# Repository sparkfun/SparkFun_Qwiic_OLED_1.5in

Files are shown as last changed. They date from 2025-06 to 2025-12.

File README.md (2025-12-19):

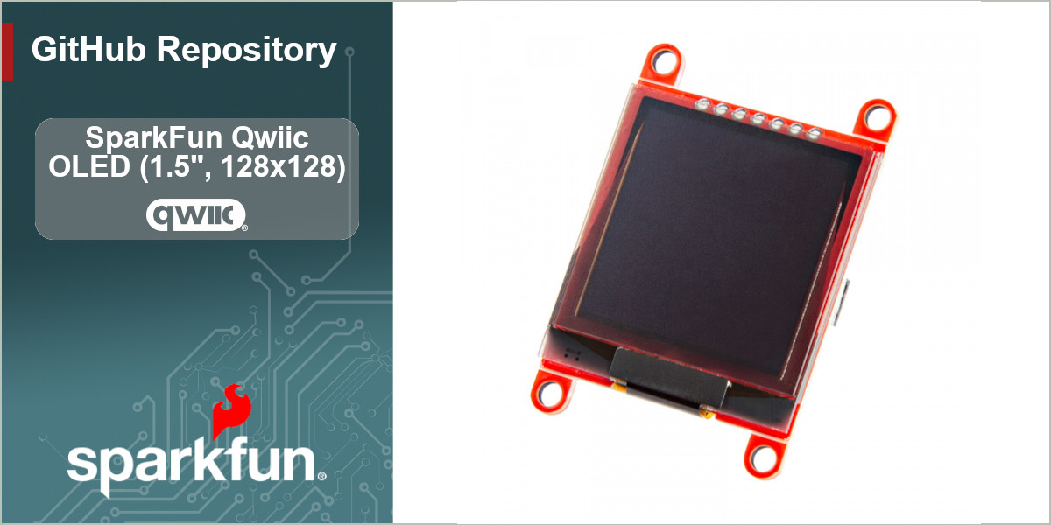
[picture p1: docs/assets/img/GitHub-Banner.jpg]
SparkFun Qwiic OLED 1.5in (https://www.sparkfun.com/sparkfun-qwiic-oled-display-1-5-in-128x128.html)


--------------------------

The SparkFun Qwiic OLED Display offers a sharp, professional user interface in a compact 1.5-inch form factor. Featuring a 128x128-pixel resolution, this monochrome white-on-black display uses Chip-on-Glass (COG) OLED technology, providing a 1:1 aspect ratio and a high-pixel-density canvas ideal for custom graphics and data plotting. Because OLED pixels emit their own light, no bulky backlight is required, resulting in superior image quality and "deeper blacks" compared to traditional LCDs.

Repository Contents
-------------------

* **/Documents** - Data sheets, additional product information
* **/Hardware** - Eagle design files (.brd, .sch)
* **/Production** - Production panel files (.brd)
* **/docs** - Documentation files for Hookup Guide content

Documentation
--------------
* **[Library](https://github.com/sparkfun/SparkFun_Qwiic_OLED_Arduino_Library)** - Arduino library for the SparkFun Qwiic OLEDs.
* **[Hookup Guide](https://docs.sparkfun.com/SparkFun_Qwiic_OLED_1.5in/introduction/#)** - Basic hookup guide for the SparkFun Qwiic OLED Display (1.5 in., 128x128).

Product Versions
----------------
* [LCD-29530](https://www.sparkfun.com/sparkfun-qwiic-oled-display-1-5-in-128x128.html) - Initial release of the Qwiic OLED Display (1.5" 128x128)

License Information
-------------------

This product is _**open source**_! 

Please review the LICENSE.md file for license information. 

If you have any questions or concerns on licensing, please contact technical support on our [SparkFun forums](https://forum.sparkfun.com/viewforum.php?f=152).

Distributed as-is; no warranty is given.

- Your friends at SparkFun.

_<COLLABORATION CREDIT>_

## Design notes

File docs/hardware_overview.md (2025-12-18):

Let's take a closer look at the OLED and other hardware included on this breakout board.

## WEO128128HWAP3N00000 OLED

This COG (Chip on Glass) OLED display from Winstar Displays is a 1.5" square monochrome white on black display. It has a 128x128 pixel dot matrix display with an active area of 28.86mm x 28.86mm. 

This OLED uses the CH1120 display driver IC. The board also includes a AP3012 boost circuit to output 12V to boost the contrast of the OLED.

## Connectors

## Power

The board's power is supplied through either one of the Qwiic connectors or through the dedicated PTH power pins (3.3V and GND). The board expects a supply voltage of 3.3V and runs at the same logic level. 

## LED

The sole LED on the board is a red LED labeled PWR. This LED illuminates when the 3.3V rail is powered.

## Solder Jumpers

This Qwiic OLED Display has five solder jumpers labeled <b>IM1</b>, <b>IM2</b>, <b>ADDR</b>, <b>LED</b> and <b>I<sup>2</sup>C</b>. The list below outlines the functionality of each jumper along with notes on their use.

* <b>IM1</b>/<b>IM2</b> - These two jumpers control the communication interface to the OLED. With both jumpers OPEN the OLED communicates over I<sup>2</sup>C. With both jumpers CLOSED the OLED communicates over SPI. Both jumpers are OPEN by default to enable the I<sup>2</sup>C interface. Both jumpers must be in the same state for either communication interface.
* <b>ADDR</b> - The ADDR jumper sets the I<sup>2</sup>C address of the OLED. The jumper is OPEN by default and sets the I<sup>2</sup>C address to <b>0x3C</b>. Close the solder jumper to change the address to <b>Ox3D</b>.
* <b>LED</b> - This solder jumper completes the power LED circuit to enable the red power LED. It is CLOSED by default. Open the jumper to disable the power LED if needed.
* <b>I<sup>2</sup>C - This three-way solder jumper pulls the I<sup>2</sup>C lines (SDA and SCL) to <b>3.3V</b> through a pair of <b>2.2k&ohm;</b> resistors. Open the jumper completely to disable the pullups on these lines.

## Board Dimensions

The main dimensions of the Qwiic OLED Display measure 1.350" x 1.475" (34.290mm x 37.465) and it has four mounting standoffs outside the main dimensions that fit a 4-40 screw.

<figure markdown>
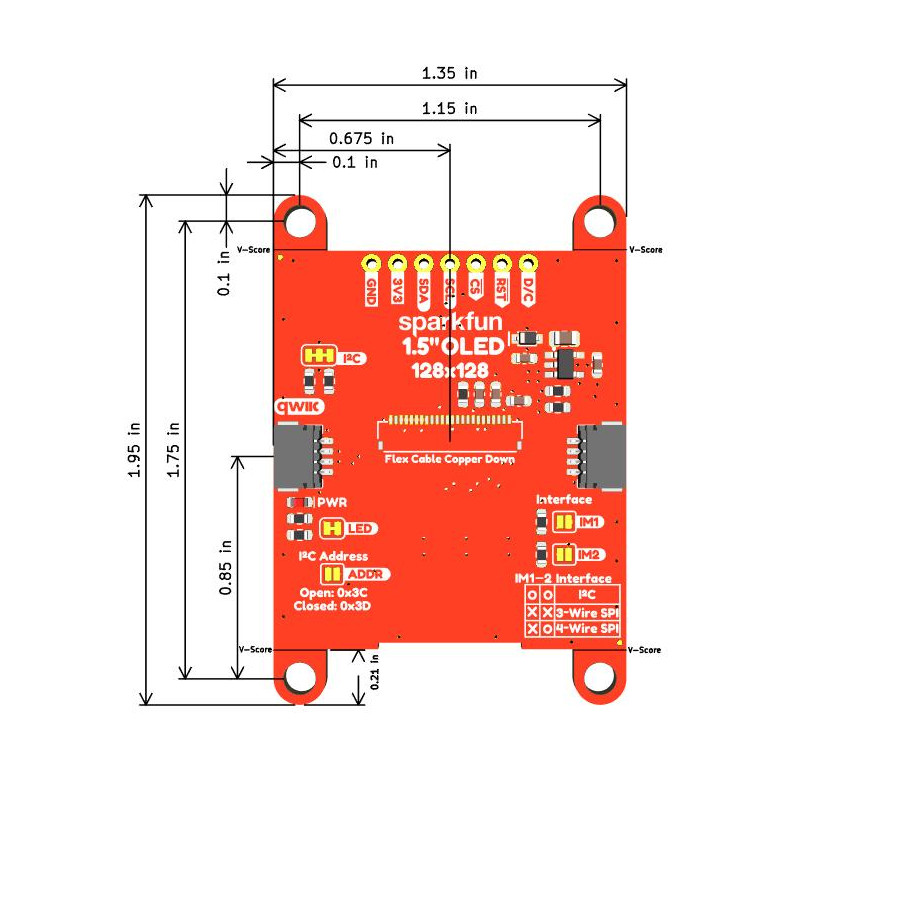
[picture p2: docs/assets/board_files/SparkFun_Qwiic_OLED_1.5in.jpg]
Board Dimensions

</figure>

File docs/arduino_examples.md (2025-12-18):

Let's take a look at a few of the examples included in the SparkFun Qwiic OLED Arduino Library

## Example 01 - Hello

The first example in the Qwiic OLED library shows the basic setup of the library and generates a simple text display of "Hello". Open the example by navigating to **File** > **Examples** > **SparkFun Qwiic OLED Arduino Library** > **Example-01_Hello**. All the examples included in the library work with the five supported Qwiic OLEDs with a simple adjustment to a couple lines in the start of the sketch. The examples default to select the Qwiic Micro OLED so we need to adjust the definition to switch to the 1.5" OLED. Comment out the line for the Qwiic Micro OLED and uncomment the line for the Qwiic 1.5" OLED like the code below:

``` c++
//QwiicMicroOLED myOLED;
//QwiicTransparentOLED myOLED;
//QwiicNarrowOLED myOLED;
//Qwiic1in3OLED myOLED;
Qwiic1in5OLED myOLED;
```
After selecting the correct OLED, select your Board and Port and click the "Upload" button. Once the code finishes uploading the display should initialize and display a static text print saying "Hello" like the photo below:

<figure markdown>
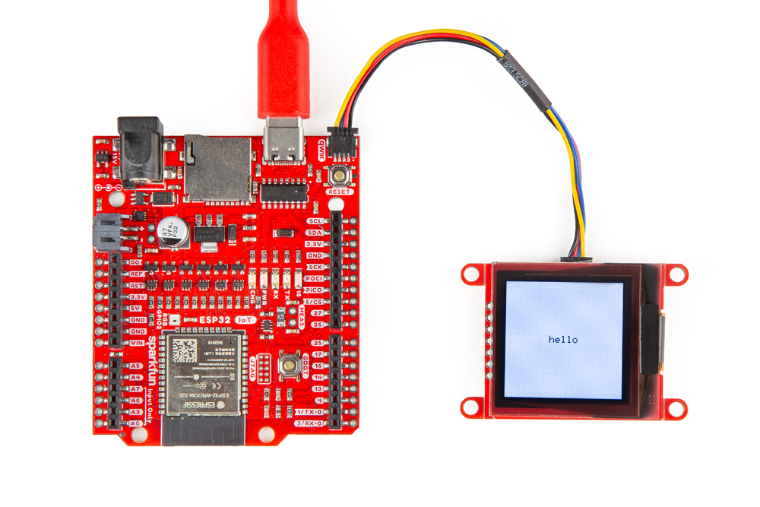
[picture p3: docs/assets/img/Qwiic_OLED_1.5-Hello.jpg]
Photo of the Qwiic OLED 1.5 displaying "Hello"

</figure>

## Example 02 - Shapes

The second example demonstrates various methods for drawing shapes using the library. Open the example by navigating to **File** > **Examples** > **SparkFun Qwiic OLED Arduino Library** > **Example-02_Shapes**. Remember we need to adjust the code to work with the OLED 1.5" so make sure to adjust the definitions like we did for Example 01 before uploading. After adjusting the OLED definition, click the "Upload" button. Once the code finishes uploading, the display will initialize and start drawing various shapes using different drawing methods to create various types of lines, rectangles and circles like the video below shows:

<figure markdown>
Short video showing the Qwiic OLED 1.5 displaying various shapes and lines
</figure>

## Example 06 - Clock

The sixth example draws a clock face on the OLED that updates roughly every second to keep time. Open the example by navigating to **File** > **Examples** > **SparkFun Qwiic OLED Arduino Library** > **Example-06_Clock**. Adjust the OLED defines to select the 1.5" display and if you want to have it keep accurate time, you can set the initial time by adjusting the initial variables for hours, minutes and seconds:

``` c++
// Use these variables to set the initial time
int hours = 11;
int minutes = 50;
int seconds = 30;
```

Upload the code and when it finishes, the display will initialize with a clock face like the image below:

<figure markdown>
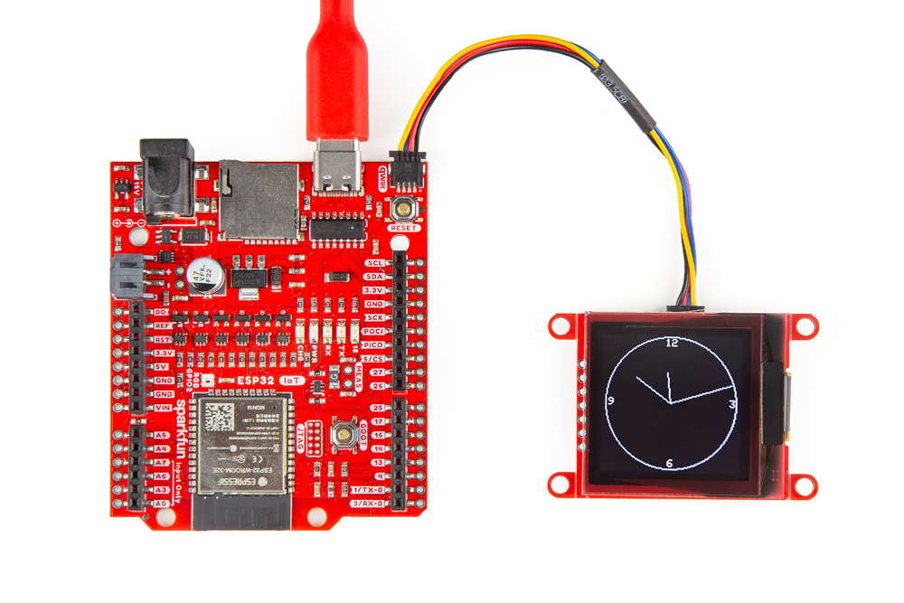
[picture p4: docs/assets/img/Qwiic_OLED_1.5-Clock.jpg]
Photo showing the OLED displaying a clock face

</figure>

## Example 07 - Cube

The last example we'll cover here is Example 07 - Cube. This example creates a cube in the center of the display that rotates around its center point. Open the example by navigating to **File** > **Examples** > **SparkFun Qwiic OLED Arduino Library** > **Example-07_Cube**. 

<figure markdown>
Short video showing the cube demo on the Qwiic OLED 1.5
</figure>

This example has plenty of variables we can adjust to change things like the size, location and rotation speed of the cube. For the video above, we doubled the size of the cube to make it easier to see. Try playing around with the different variables and re-uploading it to change the appearance and movement of the cube.

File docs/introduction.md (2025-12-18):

<figure markdown>
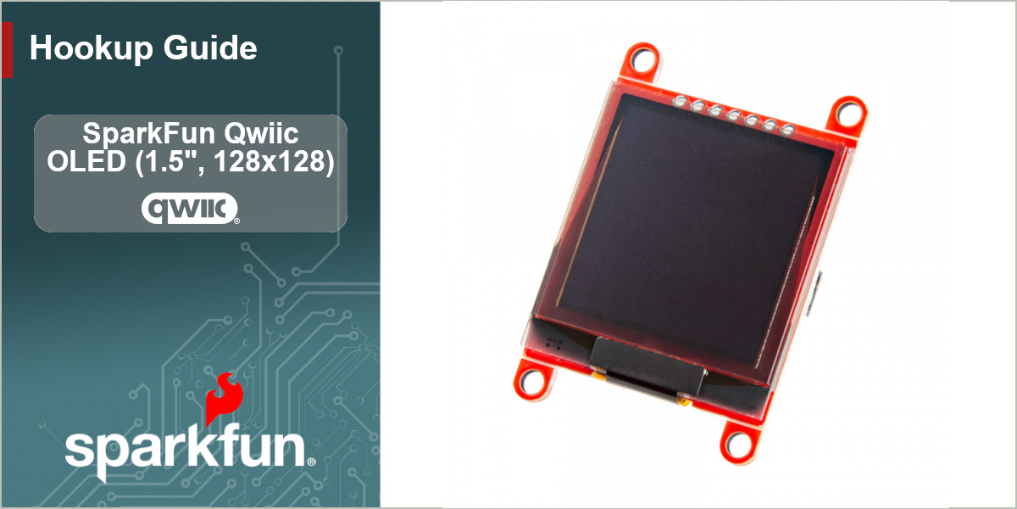
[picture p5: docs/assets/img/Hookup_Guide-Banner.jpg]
Banner Image (https://www.sparkfun.com/sparkfun-qwiic-oled-display-1-5-in-128x128.html)

</figure>

The SparkFun Qwiic OLED Display (1.5in., 128x128) is a compact, square monochrome white on black 128x128 pixel display. This COG (chip on glass) OLED display does not have a back light layer (unlike LCDs) so it’s thinner, consumes less power, and has higher contrast. 

You'll need the Qwiic OLED Display (1.5in., 128x128) along with the following products to follow along with this tutorial:

* [SparkFun RedBoard IoT - ESP32](https://www.sparkfun.com/sparkfun-redboard-plus.html) or other Arduino development board
* [Qwiic Cable]()
* [USB-C Cable](https://www.sparkfun.com/reversible-usb-a-to-c-cable-0-8m.html)

## Topics Covered

This document contains three main sections: **Quickstart Guide**, **Hardware** and **Software**. 

The Quickstart Guide assumes a working knowledge of how to assemble and use the Qwiic OLED Display with a Qwiic-enabled development board. It covers basic Qwiic assembly then jumps right into getting the necessary software packages installed to start uploading code and displaying text and images in just a few short minutes.

The Hardware pages cover a hardware overview that provides a detailed overview of the Qwiic OLED Display (1.5in., 128x128) covering all the major components on the board in detail as well as a hardware assembly page which goes over the steps required to assemble and use board with a compatible Arudino board.

The Software pages give instructions on installing the SparkFun OLED Arduino library and using the examples included in it.

## Resources and Documentation

You'll find the board design files (KiCad files & schematic), relevant documentation (datasheets, white papers, etc.) and other helpful links in the **Resources**. Lastly, the **Support** section includes a Troubleshooting page that includes any helpful tips specific to this board as well as information on how to receive technical support from SparkFun.

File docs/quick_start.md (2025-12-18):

In this Quick Start guide we'll connect the SparkFun OLED Display (1.5in., 128x128) to a SparkFun IoT RedBoard - ESP32 and use the SparkFun Qwiic OLED Arduino library to produce a rotating cube on the display.

<figure markdown>
Short video showing cube demo on the OLED
</figure>

If you're not familiar with using breakout and development boards or the Arduino IDE, refer to the [Hardware](./hardware_overview.md) & [Software](./arduino_setup.md) sections for a detailed overview of the board along with instructions on soldering to and connecting the breakout, installing and using the SparkFun MY1690X MP3 Decoder Arduino Library.

## Basic Assembly

With the Qwiic Ecosystem all you'll need to do to assemble the Qwiic OLED - 1.5" is the following steps:

* Connect the Qwiic OLED Display to the RedBoard IoT - ESP32 using a Qwiic cable.
* Connect the RedBoard IoT - ESP32 to your computer with a USB-C cable.

<figure markdown>
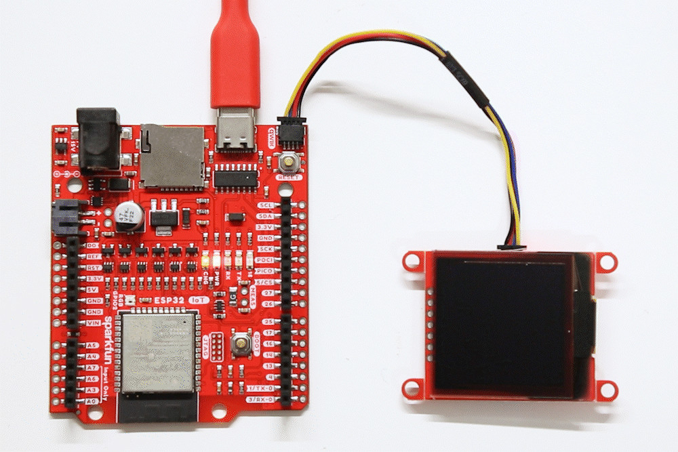
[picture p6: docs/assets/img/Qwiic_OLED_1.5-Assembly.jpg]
Completed Qwiic assembly
[]
</figure>

## Arduino Example

Let's move on to installing the SparkFun Qwiic OLED Arduino library (and boards packages if needed) to . Follow these steps to upload and run the "Cube" example.

* Install the SparkFun Qwiic OLED Arduino library using the [library manager](https://docs.arduino.cc/software/ide-v2/tutorials/ide-v2-installing-a-library/) by searching for "SparkFun Qwiic OLED".
* If you don't already have the RedBoard IoT - ESP32 board definition installed, you'll need to install the "esp32" boards package by Espressif Systems. Copy this JSON URL: <code>https://espressif.github.io/arduino-esp32/package_esp32_dev_index.json
</code> to the "Additional Boards Manager URLs" in the "Preferences" menu and then search for "esp32" in the [boards manager](https://docs.arduino.cc/software/ide-v2/tutorials/ide-v2-board-manager) tool and install the latest version of the "esp32 by Espressif Systems" boards package.
* Open "Example-07_Cube" from the SparkFun Qwiic OLED Arduino library folder. Comment out the line for the Qwiic Micro OLED and uncomment the line for the Qwiic 1.5" OLED like the code below:

``` c++
//QwiicMicroOLED myOLED;
//QwiicTransparentOLED myOLED;
//QwiicNarrowOLED myOLED;
//Qwiic1in3OLED myOLED;
Qwiic1in5OLED myOLED;
```

* Select your Board and Port and click the "Upload" button.

Once the code finishes compiling and uploading, the OLED should display a rotating cube similar to the video below:

<figure markdown>
Short video showing cube demo on the OLED
</figure>

This example has plenty of variables we can adjust to change things like the size, location and rotation speed of the cube. For the video above, we doubled the size of the cube to make it easier to see. Try playing around with the different variables and re-uploading it to change the appearance and movement of the cube.

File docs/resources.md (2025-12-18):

Refer to the following resources for more information about the SparkFun Qwiic OLED (1.5in., 128x128):

* [Schematic](./assets/board_files/SparkFun_Qwiic_OLED_1.5in.pdf)
* [KiCad Files](./assets/board_files/SparkFun_Qwiic_OLED_1.5in.zip)
* [Board Dimensions](./assets/board_files/SparkFun_Qwiic_OLED_1.5in.jpg)
* [Datasheet](./assets/component_documentation/WEO128128HWAP3N00000.pdf) (WEO128128HWAP3N00000)
* [Datasheet](./assets/component_documentation/CH1120.V0.9.pdf) (CH1120)
* [OLED Arduino Library](https://github.com/sparkfun/SparkFun_Qwiic_OLED_Arduino_Library)
* [GitHub Repository](https://github.com/sparkfun/SparkFun_Qwiic_OLED_1.5in)

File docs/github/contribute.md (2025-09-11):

# Contribute: Make an Augmentation!
Spot an improvement opportunity? Feel free to contribute to our open-source design and documentation. 

## :material-file-document-multiple:&nbsp;Improve our Documentation
All of this documentation can be modified by you! Please help us make it better.

* These pages are contained in the [`docs` folder](https://github.com/sparkfun/SparkFun_Qwiic_OLED_1.5in/tree/main/docs) of the [SparkFun Qwiic OLED Display (1.5in, 128x128) repository](https://github.com/sparkfun/SparkFun_Qwiic_OLED_1.5in).

<!-- ### :material-source-pull:&nbsp;Submit a Correction -->
### Submit a Correction

1. With a GitHub account, [fork this repository](https://github.com/sparkfun/SparkFun_Qwiic_OLED_1.5in/fork).
2. Add your corrections or improvements to the markdown file.
3. File a pull request with your changes, and enjoy making the ~~words~~ ~~worlds~~ world a better place.
	* Once received, the documentation specialist will automatically be notified.
	* We will review your suggested improvements to make sure they are correct and fit within our documentation standards.

## :material-cog:&nbsp;Improve our Hardware Design
All of our designs are open-source! Please help us make it better.

* Our board design files are contained in the [`Hardware` folder](https://github.com/sparkfun/SparkFun_Qwiic_OLED_1.5in/tree/main/Hardware) of the [SparkFun Qwiic OLED Display (1.5in, 128x128) repository](https://github.com/sparkfun/SparkFun_Qwiic_OLED_1.5in).

<!-- ### :material-source-pull:&nbsp;Submit a Design Enhancement -->
### Submit a Design Enhancement

1. With a GitHub account, [fork this repository](https://github.com/sparkfun/SparkFun_Qwiic_OLED_1.5in/fork).
2. Add your design augmentation(s)
3. File a pull request with your changes, and enjoy making the ~~words~~ ~~worlds~~ world a better place.
	1. Once received, the engineer in charge of the original design will automatically be notified.
	2. We will review your suggested improvement(s) to verify that they are within our board design standards and meet our product design requirements.
	3. If approved, we will flag these changes for our next board revision. Congrats! 🍻

		!!! info
			Even if your suggestion is accepted, these changes may not be immediately available for purchase. We may have to cycle through our current product inventory first.

## Contributors&nbsp;:clap:
Let's provide some recognition to the contributors for this project!

GitHub Contributors Image
<br>


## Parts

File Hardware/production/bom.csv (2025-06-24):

Designator | Footprint | Quantity | Value | LCSC Part #
C1, C2 | 603 | 2 | 1.0uF
C3, C4, C5 | 603 | 3 | 4.7uF
D1 | 603 | 1 | Red
D2 | SOD-323 | 1 | PMEG4005EJ
J1, J2 | JST_SMD_1.0mm-4_Black | 2 | Qwiic_RA
J3 | 1x06 | 1 | Conn_01x06
J4 | FPC_0.5mm-24 | 1 | Conn_01x24_FPC
L1 | 805 | 1 | 10uH
R10, R11, R7 | 603 | 3 | 10k
R12 | 603 | 1 | 68.1k
R3 | 603 | 1 | 4.7k
R4, R5 | 603 | 2 | 2.2k
R6 | 603 | 1 | 569k
R9 | 603 | 1 | 7.5k
U5 | SOT23-5 | 1 | AP3012

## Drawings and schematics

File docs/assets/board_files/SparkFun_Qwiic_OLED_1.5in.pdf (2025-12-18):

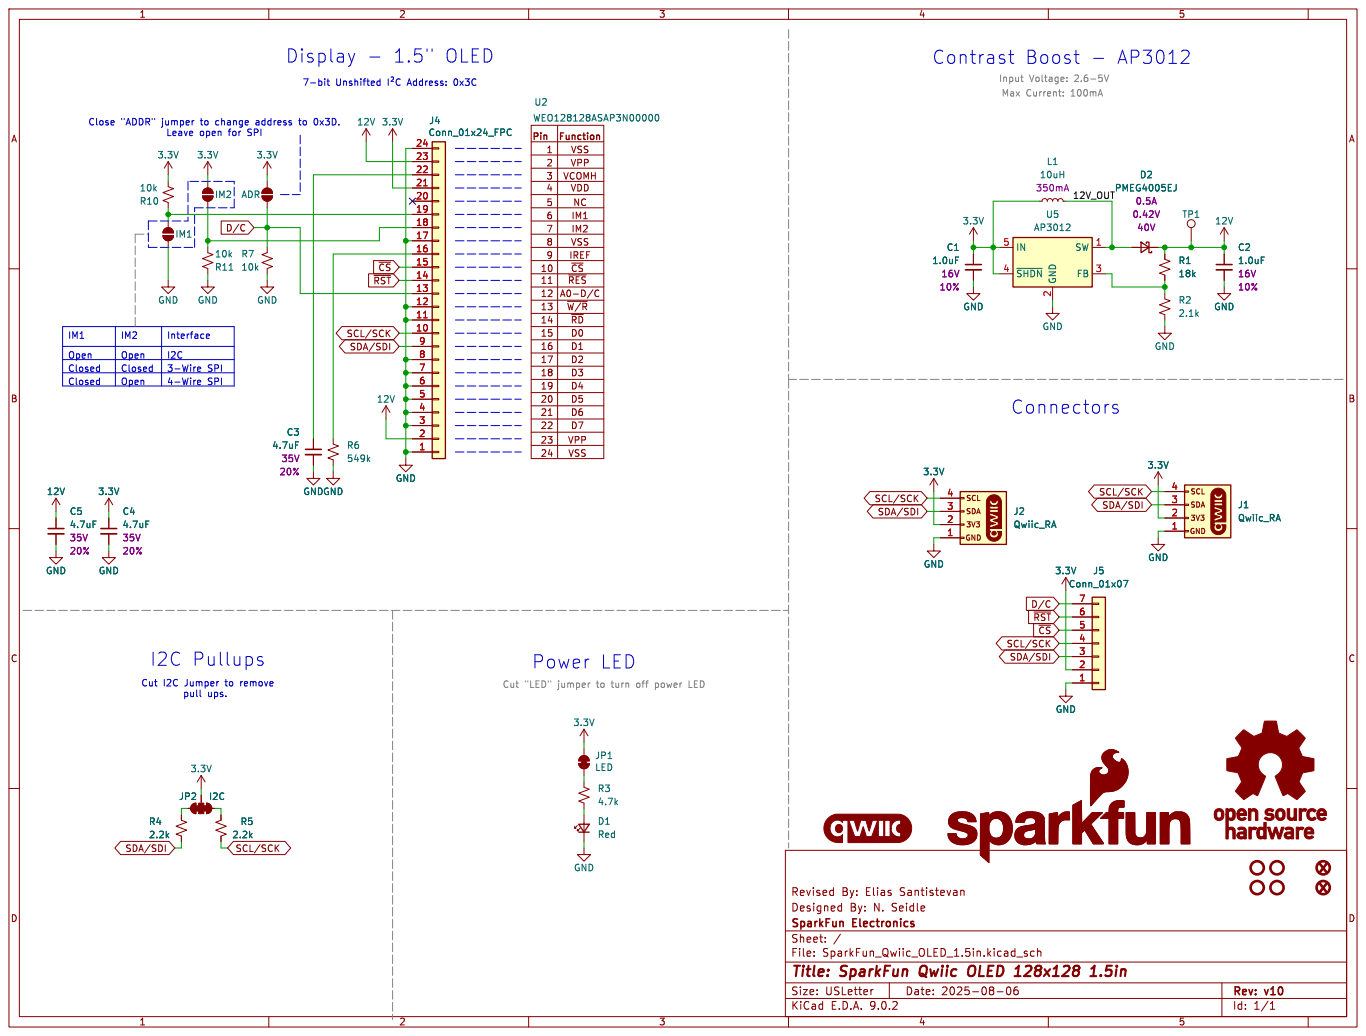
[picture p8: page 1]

Input Voltage: 2.6-5V Max Current: 100mA Contrast Boost - AP3012

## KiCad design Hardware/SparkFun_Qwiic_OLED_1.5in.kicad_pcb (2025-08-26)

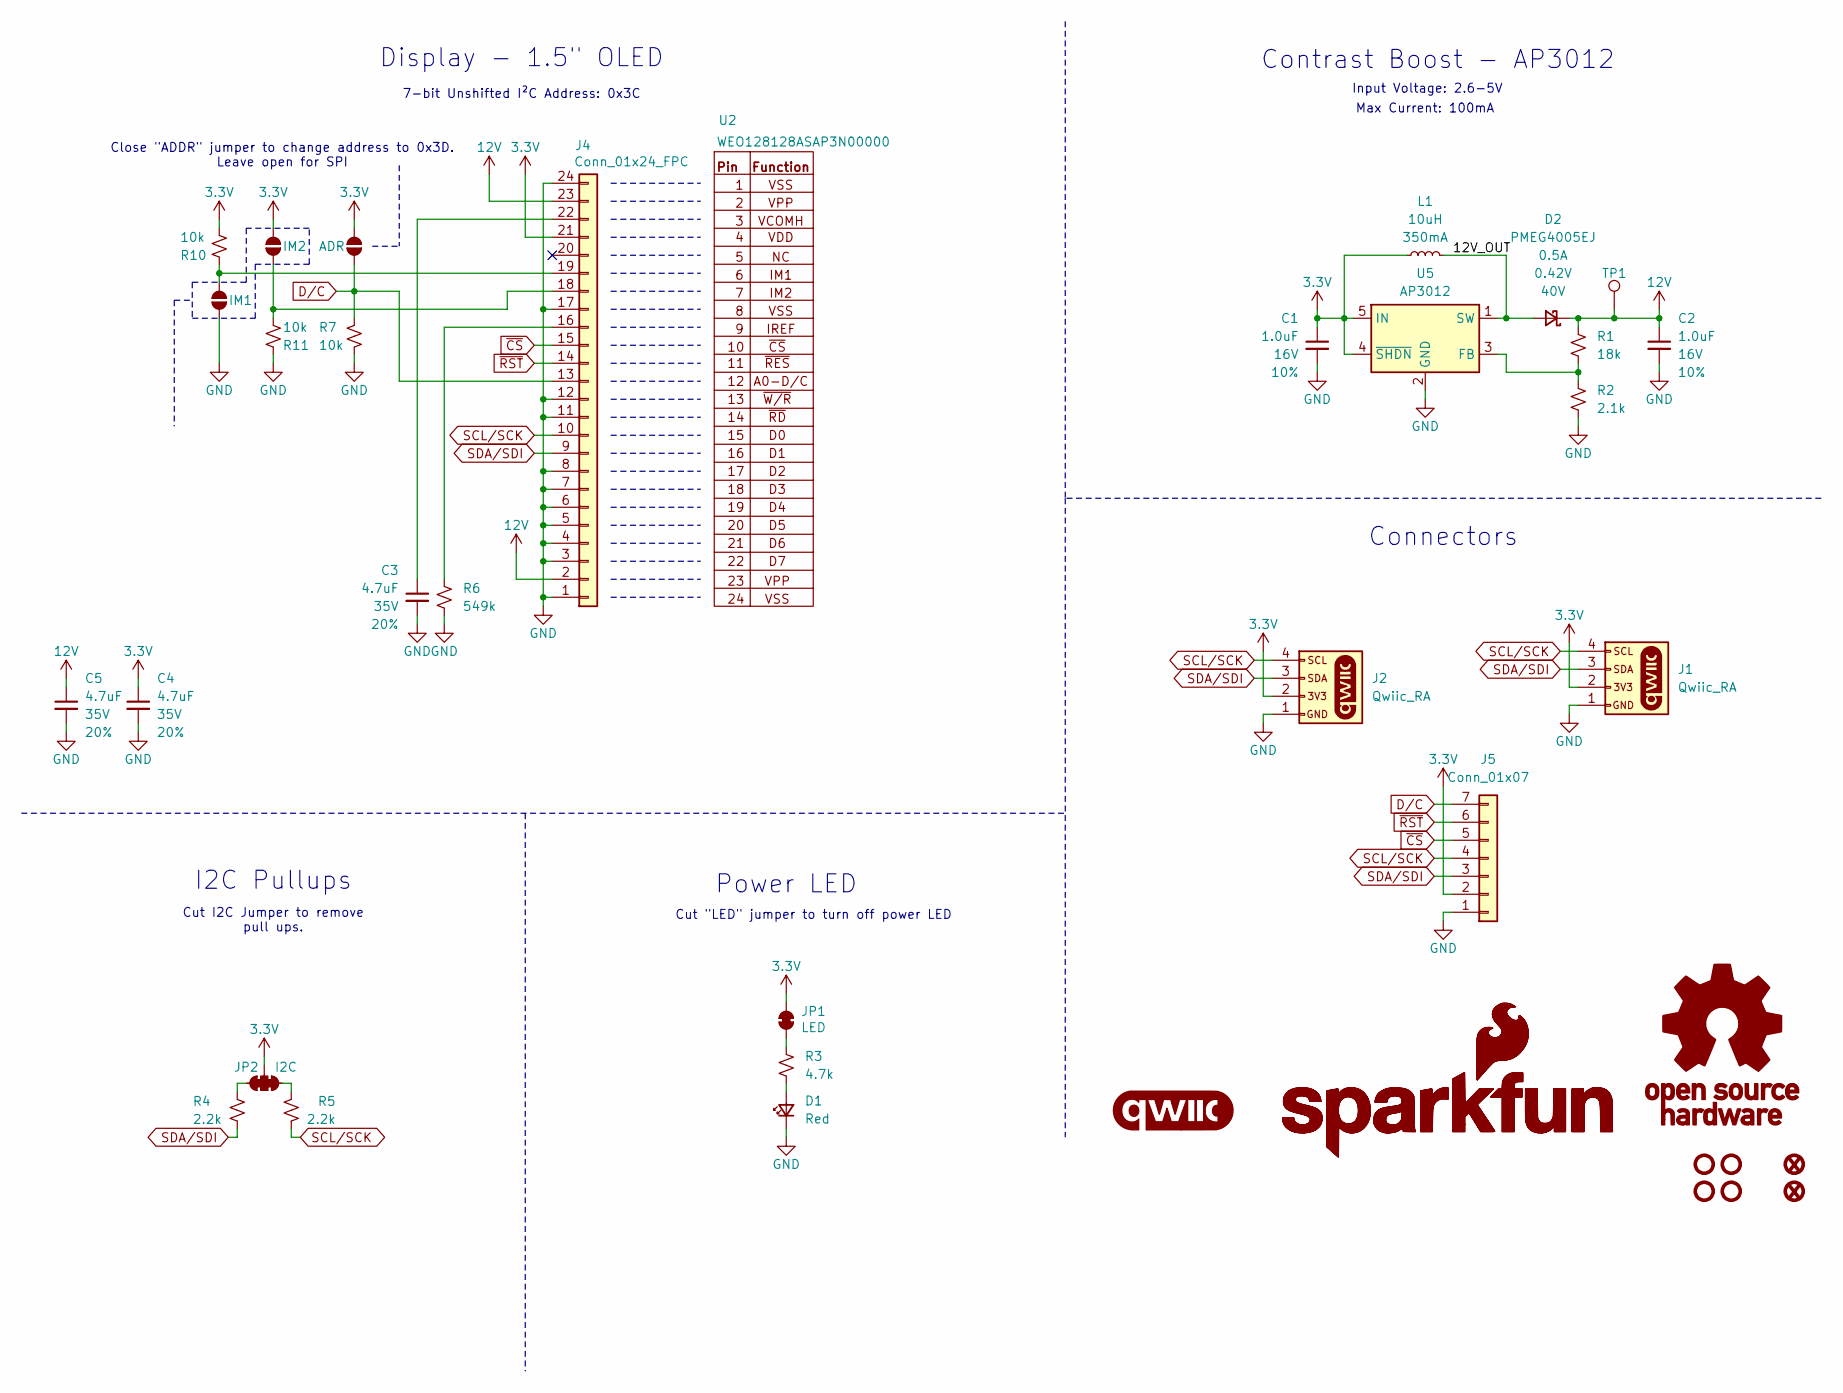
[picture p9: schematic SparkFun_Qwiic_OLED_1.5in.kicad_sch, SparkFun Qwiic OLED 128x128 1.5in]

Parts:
C1, C2: 1.0uF; C_0603_1608Metric; Voltage 16V; Tolerance 10%
C3, C4, C5: 4.7uF; C_0603_1608Metric; Voltage 35V; Tolerance 20%
D1: Red; LED_0603_1608Metric_Red
D2: PMEG4005EJ; SOD-323
FID3, FID4: Fiducial_0.5mm; Fiducial_0.5mm_Mask1mm
G1: qwiic_Logo
G2: SparkFun_Logo; SparkFun_Logo_8mm
G3: SparkFun_Logo
G4: OSHW_Logo; Creative_Commons_License
J1, J2: Qwiic_RA; JST_SMD_1.0mm-4_Black
J4: Conn_01x24_FPC; FPC_0.5mm-24
J5: Conn_01x07; 1x07
JP1: LED; Jumper_2_NC_Trace
JP2: I2C; Jumper_3_NC-2_Trace
JP3: ADR; Jumper_2_NO
JP6: IM1; Jumper_2_NO
JP7: IM2; Jumper_2_NO
L1: 10uH; C_0805_2012Metric
R1: 18k; R_0603_1608Metric
R2: 2.1k; R_0603_1608Metric
R3: 4.7k; R_0603_1608Metric
R4, R5: 2.2k; R_0603_1608Metric
R6: 549k; R_0603_1608Metric
R7, R10, R11: 10k; R_0603_1608Metric
ST1, ST2, ST3, ST4: Standoff
TP1: 1.0mm; TestPoint-1.0mm
U2: WEO128128ASAP3N00000; OLED_1.5in_128x128-Folded
U5: AP3012; SOT23-5

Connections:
3.3V: C1.1, C4.1, J1.2, J2.2, J4.21, J5.2, JP1.2 (B), JP2.2 (B), JP3.2 (B), JP7.2 (B), L1.1, R10.1, U5.4 (~SHDN), U5.5 (IN)
12V: C2.1, C5.1, D2.1 (K), J4.2, J4.23, R1.2, TP1.1
/12V_OUT: D2.2 (A), L1.2, U5.1 (SW)
D/C: J4.13, J5.7, JP3.1 (A), R7.2
GND: C1.2, C2.2, C3.2, C4.2, C5.2, D1.1 (K), J1.1, J2.1, J4.1, J4.3, J4.4, J4.5, J4.6, J4.7, J4.8, J4.11, J4.12, J4.17, J4.24, J5.1, JP6.1 (A), R2.1, R6.1, R7.1, R11.2, U5.2 (GND)
unnamed: D1.2 (A), R3.1
unnamed: J4.16, R6.2
unnamed: J4.18, JP7.1 (A), R11.1
unnamed: J4.19, JP6.2 (B), R10.2
unnamed: C3.1, J4.22
unnamed: JP1.1 (A), R3.2
unnamed: JP2.1 (A), R5.1
unnamed: JP2.3 (C), R4.2
unnamed: R1.1, R2.2, U5.3 (FB)
SCL/SCK: J1.4, J2.4, J4.10, J5.4, R5.2
SDA/SDI: J1.3, J2.3, J4.9, J5.3, R4.1
~CS: J4.15, J5.5
~RST: J4.14, J5.6

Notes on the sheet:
Input Voltage: 2.6-5V
Cut I2C Jumper to remove pull ups.
Display - 1.5" OLED
Max Current: 100mA
Cut "LED" jumper to turn off power LED
Power LED
Close "ADDR" jumper to change address to 0x3D. Leave open for SPI
7-bit Unshifted I²C Address: 0x3C
Connectors
I2C Pullups
Contrast Boost - AP3012

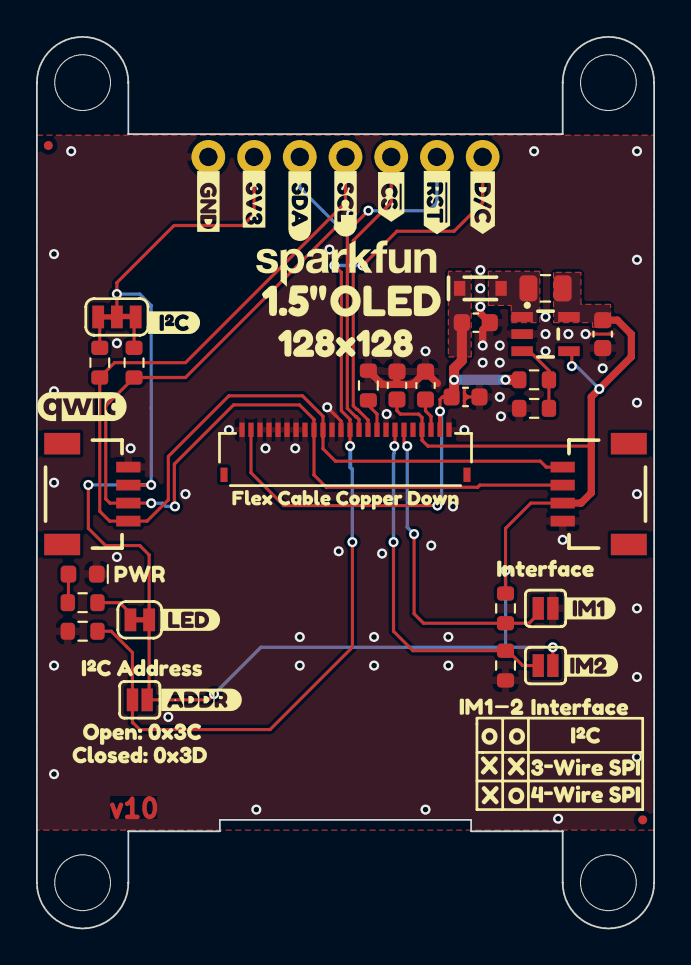
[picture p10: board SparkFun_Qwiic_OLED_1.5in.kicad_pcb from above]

Board: 2 copper layers, 34.3 x 49.5 mm, 70 parts (1 on the bottom side), 18 nets.

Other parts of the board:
kibuzzard-65A8A8B4: G***; kibuzzard-65A8A8B4
kibuzzard-67BF7EBF: G***; kibuzzard-67BF7EBF
kibuzzard-67BF7ED9: G***; kibuzzard-67BF7ED9
kibuzzard-67BF7F2F: G***; kibuzzard-67BF7F2F
kibuzzard-67BF7F13: G***; kibuzzard-67BF7F13
kibuzzard-680E7A4B: G***; kibuzzard-680E7A4B
kibuzzard-680E7A69: G***; kibuzzard-680E7A69
kibuzzard-680FC73E: G***; kibuzzard-680FC73E
kibuzzard-680FC89E: G***; kibuzzard-680FC89E
kibuzzard-680FC883: G***; kibuzzard-680FC883
kibuzzard-680FC897: G***; kibuzzard-680FC897
kibuzzard-680FC957: G***; kibuzzard-680FC957
kibuzzard-680FCA9D: G***; kibuzzard-680FCA9D
kibuzzard-680FCA96: G***; kibuzzard-680FCA96
kibuzzard-680FCADD: G***; kibuzzard-680FCADD
kibuzzard-680FCAEB: G***; kibuzzard-680FCAEB
kibuzzard-684C656A: G***; kibuzzard-684C656A
kibuzzard-685B1775: G***; kibuzzard-685B1775
kibuzzard-6893A61C, kibuzzard-6893A61C#2, kibuzzard-6893A61C#3: G***; kibuzzard-6893A61C
kibuzzard-689381EF, kibuzzard-689381EF#2, kibuzzard-689381EF#3: G***; kibuzzard-689381EF
kibuzzard-6851867B: G***; kibuzzard-6851867B
kibuzzard-6851871B: G***; kibuzzard-6851871B
kibuzzard-6893822D: G***; kibuzzard-6893822D
kibuzzard-6893824B: G***; kibuzzard-6893824B
kibuzzard-68518672: G***; kibuzzard-68518672
kibuzzard-68938236: G***; kibuzzard-68938236
kibuzzard-68938244: G***; kibuzzard-68938244
kibuzzard-68938257: G***; kibuzzard-68938257
kibuzzard-68938266: G***; kibuzzard-68938266
kibuzzard-68938270: G***; kibuzzard-68938270

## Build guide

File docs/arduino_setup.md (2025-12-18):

!!! arduino
    This example assumes you are using the latest version of the Arduino IDE on your desktop. If this is your first time using Arduino IDE, library, or board add-on, please review the following tutorials.

    - [Installing the Arduino IDE](https://learn.sparkfun.com/tutorials/installing-arduino-ide)
    - [Installing an Arduino Library](https://learn.sparkfun.com/tutorials/installing-an-arduino-library)
    - [Installing Board Definitions in the Arduino IDE](https://learn.sparkfun.com/tutorials/installing-board-definitions-in-the-arduino-ide)

## SparkFun Qwiic OLED Arduino Library

The SparkFun Qwiic OLED Arduino Library is a single graphics module that supports all SparkFun OLED boards based on the SSD1306 from Solomon Systech. You can install the library with the Arduino [Library manager](https://docs.arduino.cc/software/ide-v2/tutorials/ide-v2-installing-a-library/) tool by searching for "SparkFun Qwiic OLED". If you'd prefer a manual install, you can download a ZIP of the library [here](https://github.com/sparkfun/SparkFun_Qwiic_OLED_Arduino_Library/archive/refs/heads/main.zip).

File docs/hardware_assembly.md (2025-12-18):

## Qwiic Assembly

With the Qwiic Ecosystem all you'll need to do to assemble the Qwiic OLED - 1.5" is connect the Qwiic OLED Display to the RedBoard IoT - ESP32 using a Qwiic cable. Next, connect the RedBoard IoT - ESP32 to your computer with a USB-C cable:

<figure markdown>
Photo of the completed Qwiic assembly
</figure>

## Soldered Assembly

??? note "New to soldering?"
	If you have never soldered before or need a quick refresher, check out our [How to Solder: Through-Hole Soldering](https://learn.sparkfun.com/tutorials/how-to-solder-through-hole-soldering) guide.
	<p align="center">
		<a href="https://learn.sparkfun.com/tutorials/5">
		Tutorial's thumbnail<br>
        How to Solder: Through-Hole Soldering</a>
	</p>

Users who prefer a soldered connection or want to communicate with the display over SPI will need to carefully solder to the 0.1" PTH header on the side of the board. The glass of the display overhangs these pins slightly so you'll need to take great care when soldering to avoid damaging the display. The OLED is adhered to the board with a double-sided adhesive so we recommend using a precision crafting knife (think X-ACTO or similar knives) to carefully separate the OLED from the board prior to soldering.

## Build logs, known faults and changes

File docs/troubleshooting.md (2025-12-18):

## Qwiic OLED Arduino Library

The SparkFun Qwiic OLED Arduino library supports several different OLED breakouts. Each example includes definitions for all supported OLEDs so make sure you've adjusted those definitions to switch to the 1.5" OLED. Comment out the line for the Qwiic Micro OLED and uncomment the line for the Qwiic 1.5" OLED like the code below:

``` c++
//QwiicMicroOLED myOLED;
//QwiicTransparentOLED myOLED;
//QwiicNarrowOLED myOLED;
//Qwiic1in3OLED myOLED;
Qwiic1in5OLED myOLED;
```

## General Troubleshooting

!!! note
    <span class="glyphicon glyphicon-question-sign" aria-hidden="true"></span>
        <strong> Not working as expected and need help? </strong> <br /><br />

    If you need technical assistance and more information on a product that is not working as you expected, we recommend heading on over to the <a href="https://community.sparkfun.com/">SparkFun Forums</a> to get help from our Technical Support team and community. If this is your first visit, you'll need to create a forum account to search product forums and post questions.<br /><br />

    <div style="text-align: center"><a href="https://community.sparkfun.com/" class="md-button md-button--primary">Log Into SparkFun Forums</a></div>

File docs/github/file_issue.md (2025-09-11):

# Did we make a mistake?

Spot something wrong? Please let us know. 

## Discrepancies in the Documentation

All of our documentation can be modified by you! Please help us make it better.

* The documentation files for these pages are contained in the [`docs` folder](https://github.com/sparkfun/SparkFun_Qwiic_OLED_1.5in/tree/main/docs) of the [SparkFun Qwiic OLED Display (1.5in, 128x128) repository](https://github.com/sparkfun/SparkFun_Qwiic_OLED_1.5in).

### 🔍 Spot something wrong?

If a section of the documentation is incorrect, please [open an issue](https://github.com/sparkfun/SparkFun_Qwiic_OLED_1.5in/issues) and let us know.

### Do you have a suggested correction?

1. With a GitHub account, [fork this repository](https://github.com/sparkfun/SparkFun_Qwiic_OLED_1.5in/fork).
2. Add your correction(s) or improvement(s) to the markdown file(s)
3. File a pull request with your changes, and enjoy making the ~~words~~ ~~worlds~~ world a better place.
	* Once received, the documentation specialist will automatically be notified.
	* We will review your suggested improvement(s) to make sure they are correct and fit within our documentation standards.

## Problems in the Hardware Design

All of our designs are open-source! Please help us make it better.

* Our board design files are contained in the [`Hardware` folder](https://github.com/sparkfun/SparkFun_Qwiic_OLED_1.5in/tree/main/Hardware) of the [SparkFun Qwiic OLED Display (1.5in, 128x128) repository](https://github.com/sparkfun/SparkFun_Qwiic_OLED_1.5in).

### Does something not make sense? 🤔

If part of the design is confusing, please [open an issue](https://github.com/sparkfun/SparkFun_Qwiic_OLED_1.5in/issues) and let us know.

### Did we forget to include an important function of the board? 🤦

If part of the board's functionality is missing, please [open an issue](https://github.com/sparkfun/SparkFun_Qwiic_OLED_1.5in/issues) and file a feature request.

!!! tip "Design Considerations"
	Please keep in mind that we may intentionally exclude certain functions of the board to meet our product design requirements.
	
	* *For example, our Qwiic Micro boards are intended to fit on a small board layout and only use I<sup>2</sup>C communication; therefore, we may not have the SPI and interrupt pins available for users.*

### Do you wish to contribute directly to improving the board design?

1. With a GitHub account, [fork this repository](https://github.com/sparkfun/SparkFun_Qwiic_OLED_1.5in/fork).
2. Add your design augmentation(s)
3. File a pull request with your changes, and enjoy making the ~~words~~ ~~worlds~~ world a better place.
	1. Once received, the engineer in charge of the original design will automatically be notified.
	2. We will review your suggested improvement(s) to verify that they are within our board design standards and meet our product design requirements.
	3. If approved, we will flag these changes for our next board revision. Congrats! 🍻

		!!! info
			Even if your suggestion is accepted, these changes may not be immediately available for purchase. We may have to cycle through our current product inventory first.

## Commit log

2025-06-11 Updates the display part to be it's own symbol
    [SparkFun_Qwiic_OLED_1.5in.kicad_sch]
2025-06-11 Removes connector from OLED symbol
    [SparkFun_Qwiic_OLED_1.5in.kicad_pcb, SparkFun_Qwiic_OLED_1.5in.kicad_sch]
2025-06-13 Removes connector from OLED symbolbol and footprint
    [SparkFun_Qwiic_OLED_1.5in.kicad_pcb, SparkFun_Qwiic_OLED_1.5in.kicad_sch]
2025-06-13 Aligns the power circuitry to the IC's specification
    [SparkFun_Qwiic_OLED_1.5in.kicad_pcb, SparkFun_Qwiic_OLED_1.5in.kicad_sch]
2025-06-13 Routes the power circuitry
    [SparkFun_Qwiic_OLED_1.5in.kicad_pcb, SparkFun_Qwiic_OLED_1.5in.kicad_sch]
2025-06-13 Adds another pour for 3.3V at the power circuitry
    [SparkFun_Qwiic_OLED_1.5in.kicad_pcb]
2025-06-13 Routes all traces
    [SparkFun_Qwiic_OLED_1.5in.kicad_pcb]
2025-06-13 Cleans up the routing
    [SparkFun_Qwiic_OLED_1.5in.kicad_pcb]
2025-06-13 Moves some silk
    [SparkFun_Qwiic_OLED_1.5in.kicad_pcb]
2025-06-17 Adds vias, moves silk around, moves version to v01
    [SparkFun_Qwiic_OLED_1.5in.kicad_pcb, SparkFun_Qwiic_OLED_1.5in.kicad_sch]
2025-06-17 Changes the 12V_OUT label to be more discrete
    [SparkFun_Qwiic_OLED_1.5in.kicad_pcb, SparkFun_Qwiic_OLED_1.5in.kicad_sch]
2025-06-24 Updates the text within the schematic to be more clear
    [SparkFun_Qwiic_OLED_1.5in.kicad_sch]
2025-06-24 Fixes board outline
    [SparkFun_Qwiic_OLED_1.5in.kicad_pcb]
2025-06-24 Fixes some DRC errors
    [SparkFun_Qwiic_OLED_1.5in.kicad_pcb]
2025-06-24 Moves some vias so that it doesn't interfere with silk
    [SparkFun_Qwiic_OLED_1.5in.kicad_pcb]
2025-06-24 Adds bom positions and list for ordering
    [bom.csv, designators.csv, positions.csv]
2025-06-24 Adds no-connect on pin 5, adds prod-id value for 569k resistor
    [SparkFun_Qwiic_OLED_1.5in.kicad_pcb, SparkFun_Qwiic_OLED_1.5in.kicad_sch]
2025-06-24 Updates PCB with aforementioned changes
    [SparkFun_Qwiic_OLED_1.5in.kicad_pcb]
2025-06-24 Adds D/C to PTH header for SPI funcitonality
    [SparkFun_Qwiic_OLED_1.5in.kicad_pcb, SparkFun_Qwiic_OLED_1.5in.kicad_sch]
2025-06-26 Changes certain resistors to use more common values
    [SparkFun_Qwiic_OLED_1.5in.kicad_pcb, SparkFun_Qwiic_OLED_1.5in.kicad_sch]
2025-08-06 Updates to v10
    [SparkFun_Qwiic_OLED_1.5in.kicad_pcb, SparkFun_Qwiic_OLED_1.5in.kicad_sch]
2025-08-06 Cleans up schematic, adds table to silk for interface settings
    [SparkFun_Qwiic_OLED_1.5in.kicad_pcb, SparkFun_Qwiic_OLED_1.5in.kicad_sch]
2025-08-06 Fixes the qwiic connectors being misaligned, updates measures
    [SparkFun_Qwiic_OLED_1.5in.kicad_pcb]
2025-08-06 Increases the size of the board by .05", moves the FPC connector over .0065" so that it's in the center
    [SparkFun_Qwiic_OLED_1.5in.kicad_pcb]
2025-08-06 Centers PTH headers and screen, fixes some DRC errors created by moving the FPC connector over that small amount
    [SparkFun_Qwiic_OLED_1.5in.kicad_pcb]
2025-08-06 Fixes some text on the LED jumper
    [SparkFun_Qwiic_OLED_1.5in.kicad_sch]
2025-08-06 Adds some "O"'s to indicate open on the interface table
    [SparkFun_Qwiic_OLED_1.5in.kicad_pcb]
2025-08-12 Adds "I2C" to address in schematic, removes stub
    [SparkFun_Qwiic_OLED_1.5in.kicad_pcb, SparkFun_Qwiic_OLED_1.5in.kicad_sch]
2025-08-12 Moves the connector up .05" so that the FPC cable is a bit tighter to the PCB when the screen is secured ot it
    [SparkFun_Qwiic_OLED_1.5in.kicad_pcb]
2025-08-12 Updates the OLED footprint so that the screen to fold distance is more correctly represented
    [SparkFun_Qwiic_OLED_1.5in.kicad_pcb]
2025-08-12 Moves some small traces around
    [SparkFun_Qwiic_OLED_1.5in.kicad_pcb]
2025-08-12 Increases the size of the "V-score" text
    [SparkFun_Qwiic_OLED_1.5in.kicad_pcb]
2025-08-26 Replaces the 536k part with a 549k part
    [SparkFun_Qwiic_OLED_1.5in.kicad_pcb, SparkFun_Qwiic_OLED_1.5in.kicad_sch]

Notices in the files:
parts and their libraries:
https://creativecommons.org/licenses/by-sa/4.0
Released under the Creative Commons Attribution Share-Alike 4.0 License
